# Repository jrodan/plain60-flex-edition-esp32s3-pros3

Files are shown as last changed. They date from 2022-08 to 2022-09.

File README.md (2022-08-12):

# Plain60 Flex Edition rev2.2

## Customizing

Changed the PCB to be able to use the proS3 controller https://esp32s3.com/pros3.html and provide I2C ports and the side of the pcb together with 3 PINs directly accessible via PCB for RGB underglow lights. 

| LCSC part # | Description | Value | Package  | Amount |
| --- | --- | ----- | --- | ---:|
| C109001 | Diode | | 0805 | 65 |

## General

Plain60 Flex Edition PCB
This universal 60% PCB is designed to support as little layouts as possible without limiting usability for most users. The reason I did this is because other PCBs made for this form factor usually have so many supported layouts that it could almost qualify as swiss cheese.

It also features a fuse and an ESD protection chip to protect the MCU and other parts of the PCB.

## Features
- Fits in the TGR Unikorn
- Compatible with QMK Firmware and VIA Configurator (if you flash a VIA compatible .hex file)
- Compatible with most universal 60% cases and HHKB/WKL Tofu by KBDfans
- USB type-C
- Optional JST header for connection with daughterboard
- Footprint for optional speaker (AST1109MLTRQ)
- ESD protection and fuse
- No LEDs and no underglow
- Minimal layout support
- ISP header

## Supported layouts
Supported layouts of the Plain60-C

## Building
If you feel like building a few of these PCBs yourself, go to the 'Releases' tab and download the latest gerber files. Order those at your favourite PCB manufacturer, get the components needed (see below) and solder them on! A hot air station is not required but a soldering iron is. Flux is recommended.

## Opening the project
To open the files you will need the latest KiCAD nightly version.

## Bill of materials (BOM)
Amount is per PCB, multiply as needed.

| LCSC part # | Description | Value | Package  | Amount |
| --- | --- | ----- | --- | ---:|
| C128353 | Capacitor | 0.1uF | 0805 | 4 |
| C131056 | Capacitor | 4.7uF | 0805 | 1 |
| C215803 | Capacitor | 1uF | 0805 | 1 |
| C109001 | Diode | | 0805 | 65 |
| C261942 | Fuse | | 0805 | 1 |
| C165948 | Connector | | SMD/THT  | 1 |
| C103904 | Resistor | 10K | 0805 | 2 |
| C212411 | Resistor | 5.1K  | 0805 | 2 |
| C325772 | Resistor | 22 | 0805 | 2 |
| C44854 | MCU | 32U4  | QFP-44 | 1 |
| C7519 | ESD chip | | SOT23-6  | 1 |
| C341521 | Resonator | 16MHz | SMD | 1 |
| C92584 | Switch | | SMD | 1 |
| C160404 | Optional JST  | | SMD | 1 |

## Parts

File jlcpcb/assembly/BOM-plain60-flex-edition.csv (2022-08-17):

Comment | Designator | Footprint | LCSC
D | D1,D10,D11,D12,D13,D14,D15,D16,D17,D18,D19,D2,D20,D21,D22,D23,D24,D25,D26,D27,D28,D29,D3,D31,D32,D33,D34,D35,D36,D37,D38,D39,D4,D40,D41,D42,D43,D44,D46,D47,D48,D49,D5,D50,D51,D52,D53,D54,D55,D56,D57,D58,D59,D6,D61,D62,D63,D67,D7,D71,D72,D73,D74,D8,D9 | D_0805 | C109001
4P4C | J1 | JST_PH_S4B-PH-K_1x04_P2.00mm_Horizontal | C157926
WS2812B | LED1,LED10,LED11,LED12,LED13,LED14,LED15,LED16,LED2,LED3,LED4,LED5,LED6,LED7,LED8,LED9 | LED_WS2812B_PLCC4_5.0x5.0mm_P3.2mm | C2843785
KEYSW | K12 | CHERRY_PLATE_100H
KEYSW | K19 | CHERRY_PLATE_100H
KEYSW | K20 | CHERRY_PLATE_100H
KEYSW | K23 | CHERRY_PLATE_100H
KEYSW | K24 | CHERRY_PLATE_100H
KEYSW | K17 | CHERRY_PLATE_100H
KEYSW | K22 | CHERRY_PLATE_100H
KEYSW | K21 | CHERRY_PLATE_100H
KEYSW | K18 | CHERRY_PLATE_100H
KEYSW | K16 | CHERRY_PLATE_150H
KEYSW | K15 | CHERRY_PCB_200H
KEYSW | K8 | CHERRY_PLATE_100H
KEYSW | K10 | CHERRY_PLATE_100H
KEYSW | K14 | CHERRY_PLATE_100H
KEYSW | K5 | CHERRY_PLATE_100H
KEYSW | K13 | CHERRY_PLATE_100H
KEYSW | K11 | CHERRY_PLATE_100H
KEYSW | K9 | CHERRY_PLATE_100H
KEYSW | K7 | CHERRY_PLATE_100H
KEYSW | K6 | CHERRY_PLATE_100H
KEYSW | K4 | CHERRY_PLATE_100H
KEYSW | K2 | CHERRY_PLATE_100H
KEYSW | K1 | CHERRY_PLATE_100H
KEYSW | K3 | CHERRY_PLATE_100H
KEYSW | K62-1 | CHERRY_PLATE_100H
KEYSW | K71 | CHERRY_PLATE_125H
KEYSW | K53 | CHERRY_PLATE_100H
KEYSW | K58-1 | CHERRY_PLATE_175H
KEYSW | K57 | CHERRY_PLATE_100H
KEYSW | K54 | CHERRY_PLATE_100H
KEYSW | K56 | CHERRY_PLATE_100H
KEYSW | K52 | CHERRY_PLATE_100H
KEYSW | K55 | CHERRY_PLATE_100H
KEYSW | K61-1 | CHERRY_PLATE_150H
KEYSW | K15-1 | CHERRY_PLATE_100H
KEYSW | K74 | CHERRY_PLATE_125H
KEYSW | K73 | CHERRY_PLATE_125H
KEYSW | K28 | CHERRY_PLATE_100H
KEYSW | K48 | CHERRY_PLATE_100H
KEYSW | K25 | CHERRY_PLATE_100H
KEYSW | K36 | CHERRY_PLATE_100H
KEYSW | K33 | CHERRY_PLATE_100H
KEYSW | K63 | CHERRY_PLATE_125H
KEYSW | K44 | CHERRY_PCB_225H_F
KEYSW | K72 | CHERRY_PLATE_125H
KEYSW | K59 | CHERRY_PLATE_100H
KEYSW | K39 | CHERRY_PLATE_100H
KEYSW | K61 | CHERRY_PLATE_125H
KEYSW | K29 | CHERRY_PLATE_150H
KEYSW | K27 | CHERRY_PLATE_100H
KEYSW | K63-1 | CHERRY_PLATE_150H
KEYSW | K50 | CHERRY_PLATE_100H
KEYSW | K34 | CHERRY_PLATE_100H
KEYSW | K47 | CHERRY_PLATE_100H
KEYSW | K43 | CHERRY_PLATE_100H
KEYSW | K38 | CHERRY_PLATE_100H
KEYSW | K35 | CHERRY_PLATE_100H
KEYSW | K32 | CHERRY_PLATE_100H
KEYSW | K40 | CHERRY_PLATE_100H
KEYSW | K46 | CHERRY_PCB_225H
KEYSW | K42 | CHERRY_PLATE_100H
KEYSW | K41 | CHERRY_PLATE_100H
KEYSW | K26 | CHERRY_PLATE_100H
KEYSW | K37 | CHERRY_PLATE_100H
KEYSW | K51 | CHERRY_PLATE_100H
KEYSW | K73-1 | CHERRY_PLATE_100H
KEYSW | K62 | CHERRY_PLATE_125H
KEYSW | K49 | CHERRY_PLATE_100H
KEYSW | K72-1 | CHERRY_PLATE_150H
KEYSW | K74-1 | CHERRY_PLATE_150H
Screw | S5 | 10x5_7x2.5mm
KEYSW | K58 | CHERRY_PCB_275H
KEYSW | K67 | CHERRY_PCB_625H_F
Tofu screw | S8 | 5.5_5x2.5mm
Tofu screw | S7 | 5.5_5x2.5mm
Tofu screw | S9 | 5.5_5x2.5mm
Screw | S2 | 5.5_5x2.5mm
Screw | S1 | 5.5_5x2.5mm
Screw | S3 | 5.5_5x2.5mm
Screw | S6 | 5.5_5x2.5mm
KEYSW | K67-1 | CHERRY_PCB_700H_F
KEYSW | K44-1 | CHERRY_PCB_200H_V
KEYSW | K31-1 | CHERRY_PLATE_125H
KEYSW | K31 | CHERRY_PLATE_175H
Screw | S4 | 10x5_7x2.5mm
ProS3 | U1 | ProS3_TH

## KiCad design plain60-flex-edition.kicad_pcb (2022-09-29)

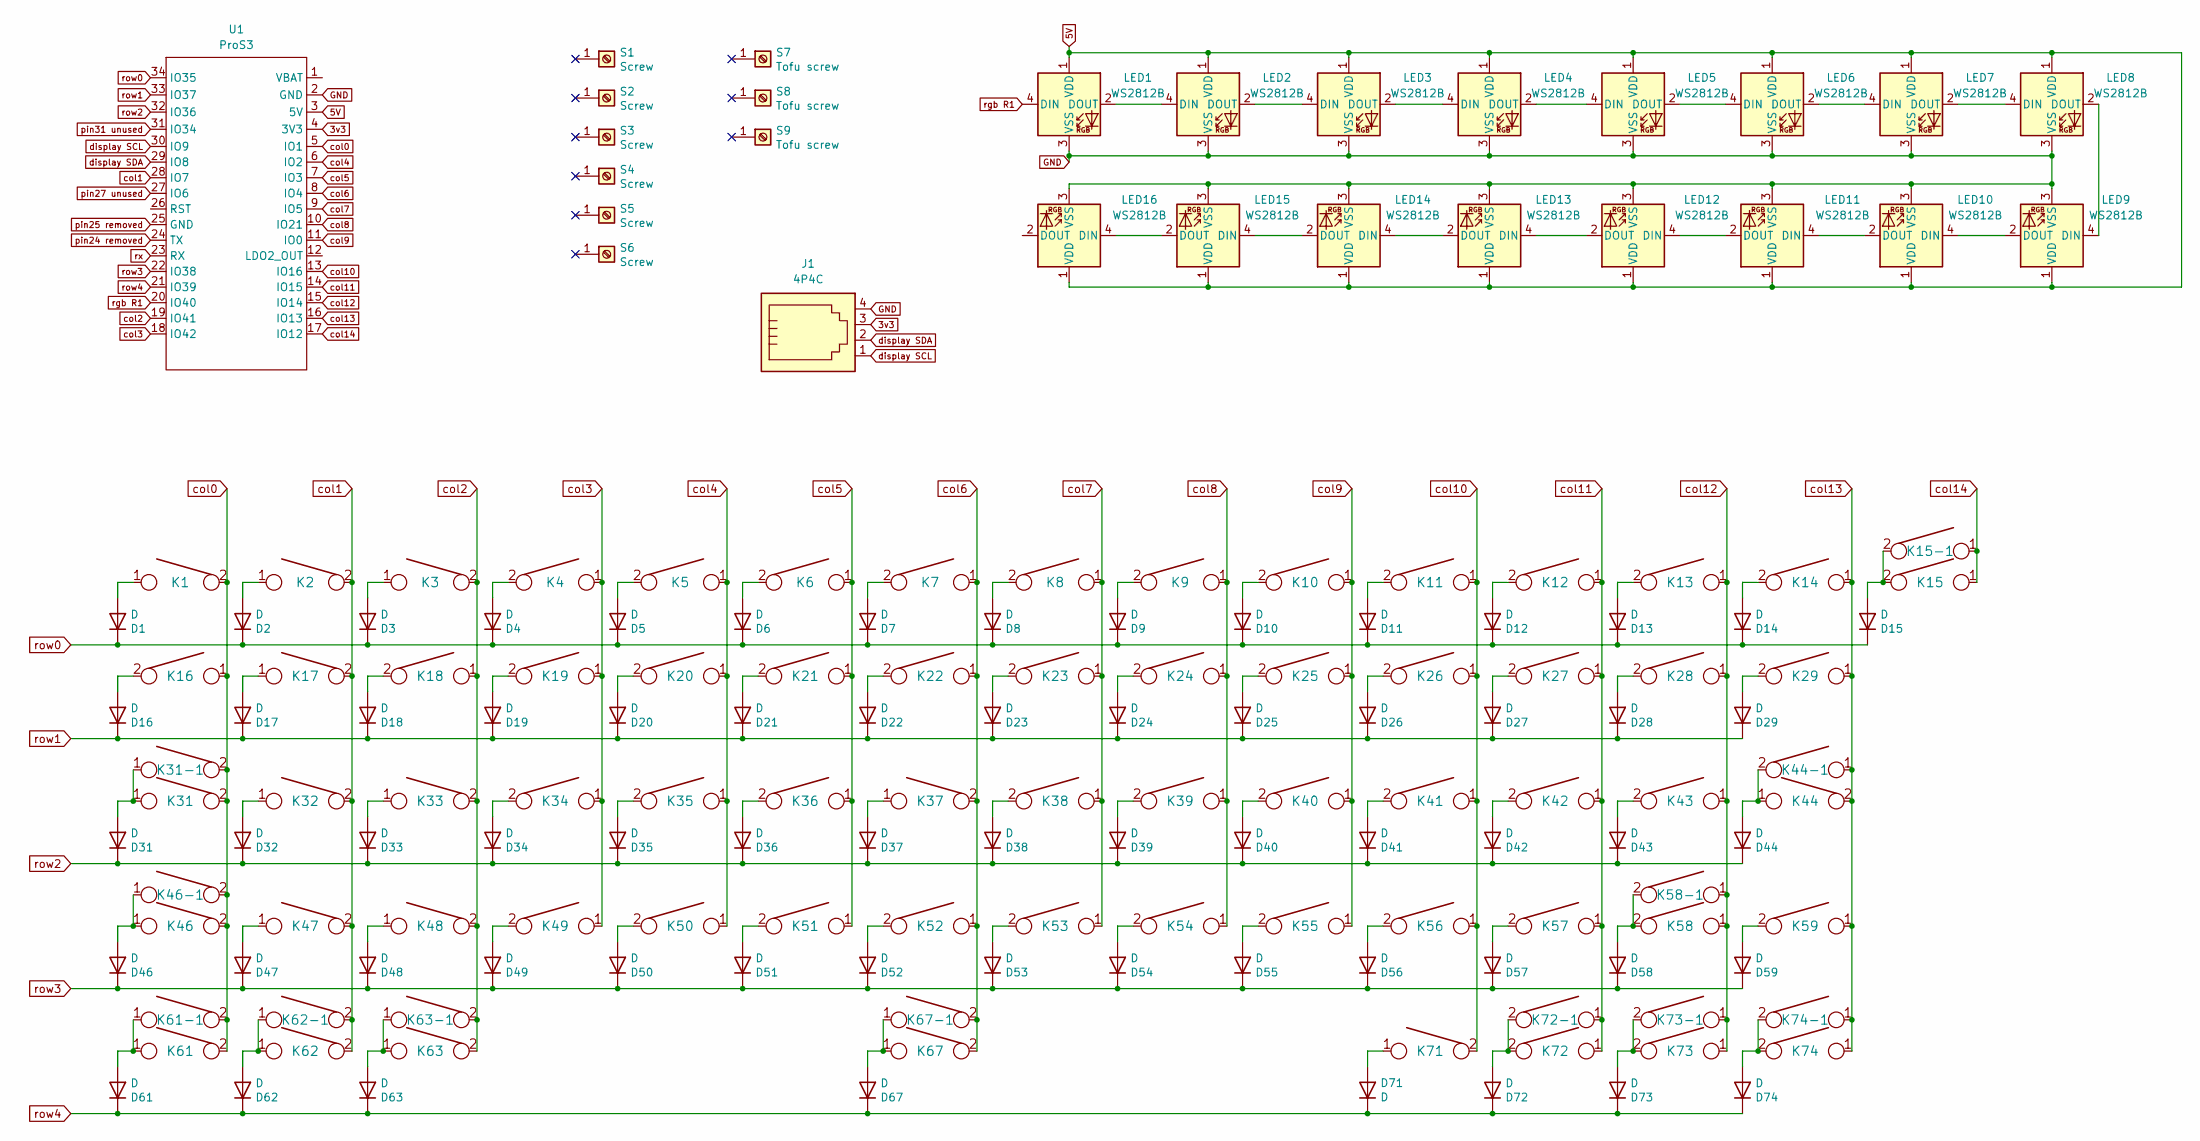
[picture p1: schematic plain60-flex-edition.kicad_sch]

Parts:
D1, D2, D3, D4, D5, D6, D7, D8, D9, D10, D11, D12, D13, D14, D15, D16, D17, D18, D19, D20, D21, D22, D23, D24, D25, D26, D27, D28, D29, D31, D32, D33, D34, D35, D36, D37, D38, D39, D40, D41, D42, D43, D44, D46, D47, D48, D49, D50, D51, D52, D53, D54, D55, D56, D57, D58, D59, D61, D62, D63, D67, D71, D72, D73, D74: D; D_0805
J1: 4P4C; JST_PH_S4B-PH-K_1x04_P2.00mm_Horizontal
K1, K2, K3, K4, K5, K6, K7, K8, K9, K10, K11, K12, K13, K14, K15-1, K17, K18, K19, K20, K21, K22, K23, K24, K25, K26, K27, K28, K32, K33, K34, K35, K36, K37, K38, K39, K40, K41, K42, K43, K47, K48, K49, K50, K51, K52, K53, K54, K55, K56, K57, K59, K62-1, K73-1: KEYSW; CHERRY_PLATE_100H
K15: KEYSW; CHERRY_PCB_200H
K16, K29, K61-1, K63-1, K72-1, K74-1: KEYSW; CHERRY_PLATE_150H
K31, K58-1: KEYSW; CHERRY_PLATE_175H
K31-1, K46-1, K61, K62, K63, K71, K72, K73, K74: KEYSW; CHERRY_PLATE_125H
K44: KEYSW; CHERRY_PCB_225H_F
K44-1: KEYSW; CHERRY_PCB_200H_V
K46: KEYSW; CHERRY_PCB_225H
K58: KEYSW; CHERRY_PCB_275H
K67: KEYSW; CHERRY_PCB_625H_F
K67-1: KEYSW; CHERRY_PCB_700H_F
LED1, LED2, LED3, LED4, LED5, LED6, LED7, LED8, LED9, LED10, LED11, LED12, LED13, LED14, LED15, LED16: WS2812B; LED_WS2812B_PLCC4_5.0x5.0mm_P3.2mm
S1, S2, S3, S6: Screw; 5.5_5x2.5mm
S4, S5: Screw; 10x5_7x2.5mm
S7, S8, S9: Tofu screw; 5.5_5x2.5mm
U1: ProS3; ProS3_TH

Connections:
3v3: J1.3, U1.4 (3V3)
5V: LED1.1 (VDD), LED2.1 (VDD), LED3.1 (VDD), LED4.1 (VDD), LED5.1 (VDD), LED6.1 (VDD), LED7.1 (VDD), LED8.1 (VDD), LED9.1 (VDD), LED10.1 (VDD), LED11.1 (VDD), LED12.1 (VDD), LED13.1 (VDD), LED14.1 (VDD), LED15.1 (VDD), LED16.1 (VDD), U1.3 (5V)
GND: J1.4, LED1.3 (VSS), LED2.3 (VSS), LED3.3 (VSS), LED4.3 (VSS), LED5.3 (VSS), LED6.3 (VSS), LED7.3 (VSS), LED8.3 (VSS), LED9.3 (VSS), LED10.3 (VSS), LED11.3 (VSS), LED12.3 (VSS), LED13.3 (VSS), LED14.3 (VSS), LED15.3 (VSS), LED16.3 (VSS), U1.2 (GND)
unnamed: D1.2 (A), K1.1
unnamed: D2.2 (A), K2.1
unnamed: D3.2 (A), K3.1
unnamed: D4.2 (A), K4.2
unnamed: D5.2 (A), K5.2
unnamed: D6.2 (A), K6.2
unnamed: D7.2 (A), K7.2
unnamed: D8.2 (A), K8.2
unnamed: D9.2 (A), K9.2
unnamed: D10.2 (A), K10.2
unnamed: D11.2 (A), K11.2
unnamed: D12.2 (A), K12.2
unnamed: D13.2 (A), K13.2
unnamed: D14.2 (A), K14.2
unnamed: D15.2 (A), K15.2, K15-1.2
unnamed: D16.2 (A), K16.2
unnamed: D17.2 (A), K17.1
unnamed: D18.2 (A), K18.2
unnamed: D19.2 (A), K19.2
unnamed: D20.2 (A), K20.2
unnamed: D21.2 (A), K21.2
unnamed: D22.2 (A), K22.2
unnamed: D23.2 (A), K23.2
unnamed: D24.2 (A), K24.2
unnamed: D25.2 (A), K25.2
unnamed: D26.2 (A), K26.2
unnamed: D27.2 (A), K27.2
unnamed: D28.2 (A), K28.2
unnamed: D29.2 (A), K29.2
unnamed: D31.2 (A), K31.1, K31-1.1
unnamed: D32.2 (A), K32.1
unnamed: D33.2 (A), K33.1
unnamed: D34.2 (A), K34.2
unnamed: D35.2 (A), K35.2
unnamed: D36.2 (A), K36.2
unnamed: D37.2 (A), K37.1
unnamed: D38.2 (A), K38.2
unnamed: D39.2 (A), K39.2
unnamed: D40.2 (A), K40.2
unnamed: D41.2 (A), K41.2
unnamed: D42.2 (A), K42.2
unnamed: D43.2 (A), K43.2
unnamed: D44.2 (A), K44.1, K44-1.2
unnamed: D46.2 (A), K46.1, K46-1.1
unnamed: D47.2 (A), K47.1
unnamed: D48.2 (A), K48.1
unnamed: D49.2 (A), K49.2
unnamed: D50.2 (A), K50.2
unnamed: D51.2 (A), K51.2
unnamed: D52.2 (A), K52.2
unnamed: D53.2 (A), K53.2
unnamed: D54.2 (A), K54.2
unnamed: D55.2 (A), K55.2
unnamed: D56.2 (A), K56.2
unnamed: D57.2 (A), K57.2
unnamed: D58.2 (A), K58.2, K58-1.2
unnamed: D59.2 (A), K59.2
unnamed: D61.2 (A), K61.1, K61-1.1
unnamed: D62.2 (A), K62.1, K62-1.1
unnamed: D63.2 (A), K63.1, K63-1.1
unnamed: D67.2 (A), K67.1, K67-1.1
unnamed: D71.2 (A), K71.1
unnamed: D72.2 (A), K72.2, K72-1.2
unnamed: D73.2 (A), K73.2, K73-1.2
unnamed: D74.2 (A), K74.2, K74-1.2
unnamed: LED1.2 (DOUT), LED2.4 (DIN)
unnamed: LED2.2 (DOUT), LED3.4 (DIN)
unnamed: LED3.2 (DOUT), LED4.4 (DIN)
unnamed: LED4.2 (DOUT), LED5.4 (DIN)
unnamed: LED5.2 (DOUT), LED6.4 (DIN)
unnamed: LED6.2 (DOUT), LED7.4 (DIN)
unnamed: LED7.2 (DOUT), LED8.4 (DIN)
unnamed: LED8.2 (DOUT), LED9.4 (DIN)
unnamed: LED10.2 (DOUT), LED11.4 (DIN)
unnamed: LED9.2 (DOUT), LED10.4 (DIN)
unnamed: LED11.2 (DOUT), LED12.4 (DIN)
unnamed: LED12.2 (DOUT), LED13.4 (DIN)
unnamed: LED13.2 (DOUT), LED14.4 (DIN)
unnamed: LED14.2 (DOUT), LED15.4 (DIN)
unnamed: LED15.2 (DOUT), LED16.4 (DIN)
col0: K1.2, K16.1, K31.2, K31-1.2, K46.2, K46-1.2, K61.2, K61-1.2, U1.5 (IO1)
col1: K2.2, K17.2, K32.2, K47.2, K62.2, K62-1.2, U1.28 (IO7)
col2: K3.2, K18.1, K33.2, K48.2, K63.2, K63-1.2, U1.19 (IO41)
col3: K4.1, K19.1, K34.1, K49.1, U1.18 (IO42)
col4: K5.1, K20.1, K35.1, K50.1, U1.6 (IO2)
col5: K6.1, K21.1, K36.1, K51.1, U1.7 (IO3)
col6: K7.1, K22.1, K37.2, K52.1, K67.2, K67-1.2, U1.8 (IO4)
col7: K8.1, K23.1, K38.1, K53.1, U1.9 (IO5)
col8: K9.1, K24.1, K39.1, K54.1, U1.10 (IO21)
col9: K10.1, K25.1, K40.1, K55.1, U1.11 (IO0)
col10: K11.1, K26.1, K41.1, K56.1, K71.2, U1.13 (IO16)
col11: K12.1, K27.1, K42.1, K57.1, K72.1, K72-1.1, U1.14 (IO15)
col12: K13.1, K28.1, K43.1, K58.1, K58-1.1, K73.1, K73-1.1, U1.15 (IO14)
col13: K14.1, K29.1, K44.2, K44-1.1, K59.1, K74.1, K74-1.1, U1.16 (IO13)
col14: K15.1, K15-1.1, U1.17 (IO12)
display SCL: J1.1, U1.30 (IO9)
display SDA: J1.2, U1.29 (IO8)
pin27 unused: U1.27 (IO6)
pin31 unused: U1.31 (IO34)
rgb R1: LED1.4 (DIN), U1.20 (IO40)
row0: D1.1 (K), D2.1 (K), D3.1 (K), D4.1 (K), D5.1 (K), D6.1 (K), D7.1 (K), D8.1 (K), D9.1 (K), D10.1 (K), D11.1 (K), D12.1 (K), D13.1 (K), D14.1 (K), D15.1 (K), U1.34 (IO35)
row1: D16.1 (K), D17.1 (K), D18.1 (K), D19.1 (K), D20.1 (K), D21.1 (K), D22.1 (K), D23.1 (K), D24.1 (K), D25.1 (K), D26.1 (K), D27.1 (K), D28.1 (K), D29.1 (K), U1.33 (IO37)
row2: D31.1 (K), D32.1 (K), D33.1 (K), D34.1 (K), D35.1 (K), D36.1 (K), D37.1 (K), D38.1 (K), D39.1 (K), D40.1 (K), D41.1 (K), D42.1 (K), D43.1 (K), D44.1 (K), U1.32 (IO36)
row3: D46.1 (K), D47.1 (K), D48.1 (K), D49.1 (K), D50.1 (K), D51.1 (K), D52.1 (K), D53.1 (K), D54.1 (K), D55.1 (K), D56.1 (K), D57.1 (K), D58.1 (K), D59.1 (K), U1.22 (IO38)
row4: D61.1 (K), D62.1 (K), D63.1 (K), D67.1 (K), D71.1 (K), D72.1 (K), D73.1 (K), D74.1 (K), U1.21 (IO39)
rx: U1.23 (RX)

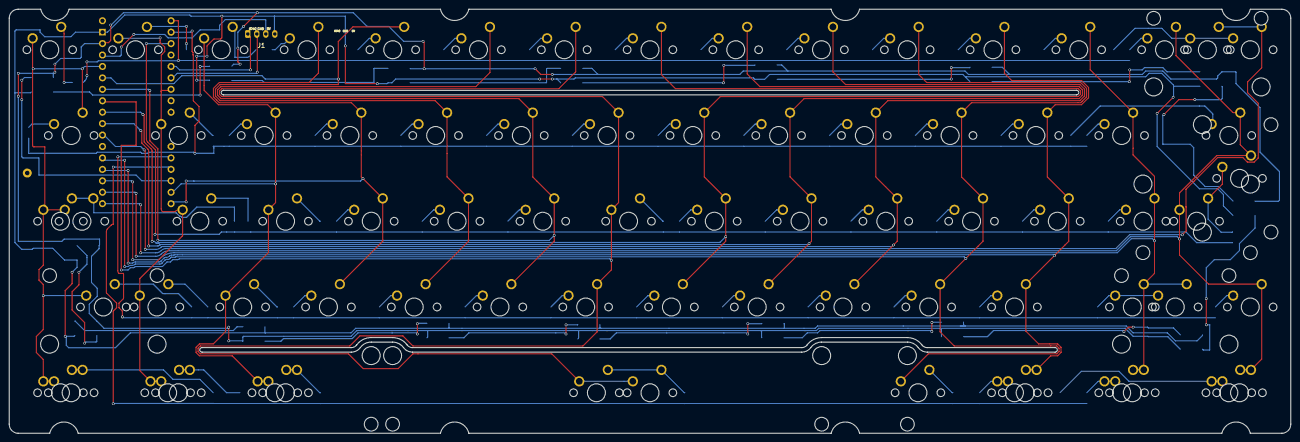
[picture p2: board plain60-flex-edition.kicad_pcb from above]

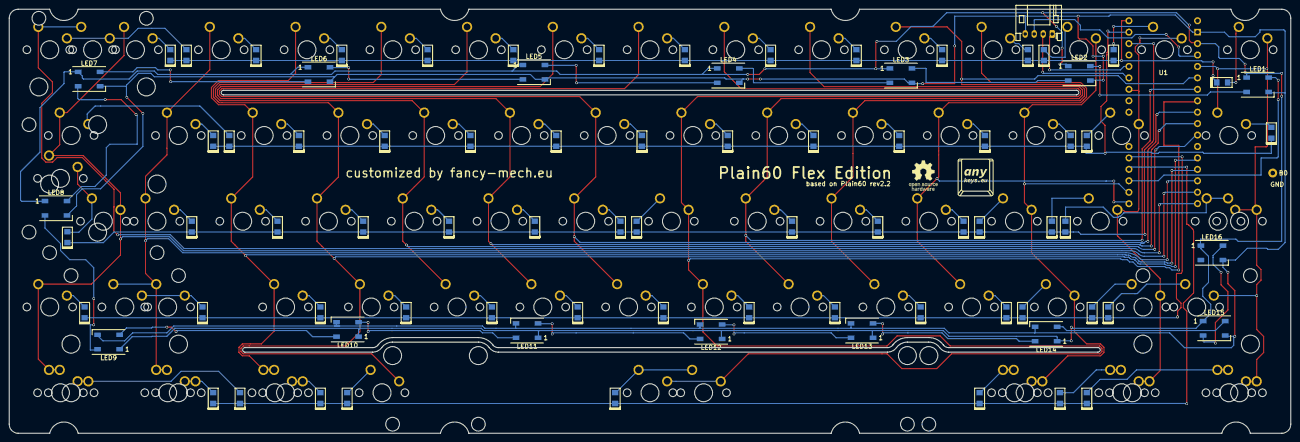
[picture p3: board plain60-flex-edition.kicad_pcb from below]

Board: 2 copper layers, 284.7 x 94.2 mm, 169 parts (84 on the bottom side), 106 nets.

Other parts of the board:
H1: B0; free_pin

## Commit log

2022-08-12 added first iteration of refactoring
    [plain60-flex-edition.kicad_pcb, plain60-flex-edition.kicad_sch]
2022-08-16 added underglow leds
    [BOM-plain60-flex-edition.csv, BOM-plain60-flex-edition.xlsx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]
2022-08-17 fix pins
    [BOM-plain60-flex-edition.csv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]
2022-09-29 fixed JST header direction
    [plain60-flex-edition.kicad_pcb, plain60-flex-edition.kicad_sch]
